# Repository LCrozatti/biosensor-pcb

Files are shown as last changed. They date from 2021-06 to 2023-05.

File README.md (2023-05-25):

# biosensor-pcb

Development of a printed circuit with NFC communication that performs cyclic voltammetry and chronoamperometry on printed electrodes with applications in amperometric biosensors.

## :books: Methodology

Kicad software will be used to make the printed circuit boards, and the first PCB has the purpose to test the code and noise involved in the sampling. The test board in question has its files in the `./placa-teste` directory. The designed test board is illustrated in the figure below:

<p align="center">
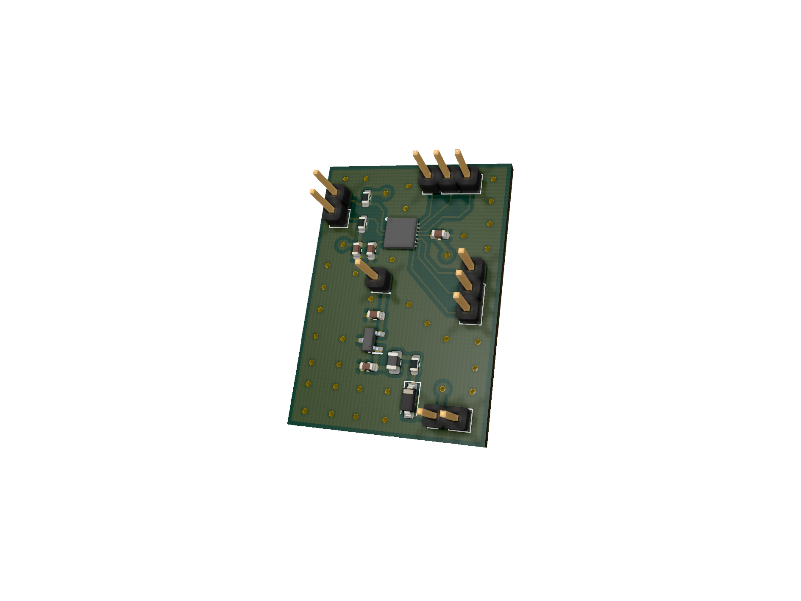
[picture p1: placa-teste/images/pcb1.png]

</p>

The first firmware involved was made based on code produced by [Linnes Lab](https://github.com/LinnesLab/LMP91000). Initially, an ATmega168PA-MU microcontroller will be used to control the potentiostat.

### :hammer: Tools

[Kicad](https://www.kicad.org/)

[C]()

[Python](https://www.python.org/)

[Jupyter](https://jupyter.org/)

[Numpy](https://numpy.org/)

[Pandas](https://pandas.pydata.org/)

[Matplotlib](https://numpy.org/)

<br />

### :test_tube: Data analysis

The data will be analyzed using the Python language, the file `./placa-teste/amostragem/eletroquimica.ipynb` contains some demonstrations on the use of python in cyclic voltammetry and chronoamperometry operations. The dataset used in this file can be accessed through the [IEEE Data Port](https://ieee-dataport.org/documents/supplementary-material-optimized-sampling-rate-voltammetry-based-electrochemical-sensing) [1].

<p align="center">
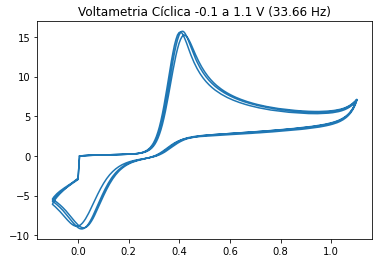
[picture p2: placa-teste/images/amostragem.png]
Amostragem

</p>

### :dart: Final prototype

The final board will have an antenna controlled by the *transponder* ST25DV64K, the control will be carried out by the microcontroller STM32L0 and the voltage control at the electrodes will be given through the programmable potentiostat LMP91000. The main study in this phase is the possibility of *energy harvesting*, leading to a circuit with low energy consumption.

### :iphone: App

The application in question will be built using the React-Native *framework*, along with the [react-native-nfc-manager](https://github.com/whitedogg13/react-native-nfc-manager) library. Its beginning has already been given with some reading tests..

<p align="center">
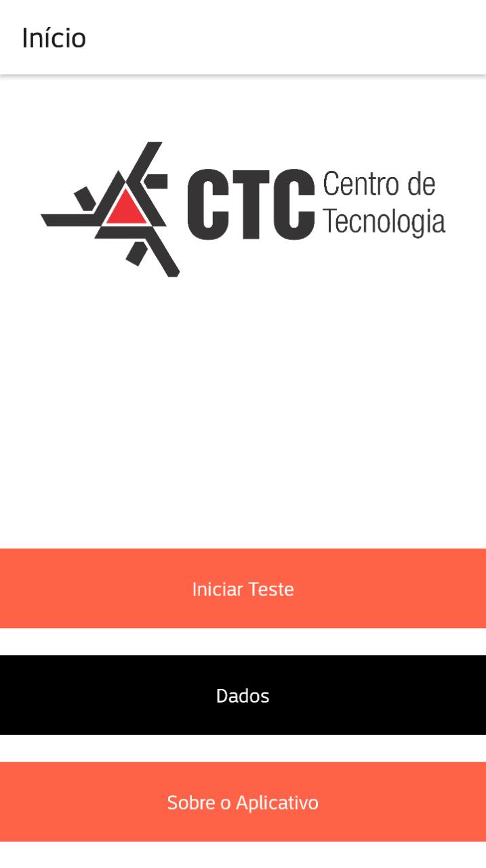
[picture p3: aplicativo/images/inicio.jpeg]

</p>

## :hourglass: Timeline

### 06/06/2021

The repository was created and updated with data from the test board.

### 13/09/2021

The soldering of the components has been completed and now some tests are being done to confirm the code. There were some problems in the negative polarization part and I will now work on the IntZ variable to make this possible (67% Vref - when we work with negative polarization). So the positive bias is working and it is possible to do a "half" cyclic voltammetry.

<p align="center">
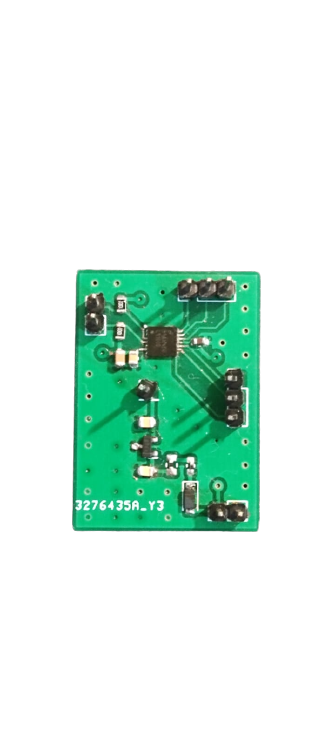
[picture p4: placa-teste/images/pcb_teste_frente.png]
placa_teste_frente

</p>

### 12/10/2021

Another test was made and is possible to see that the potential between WE and RE is sweeping among -490 mV and 490 mV, demonstrating that the board is well functioning (24% of the reference voltage that is 2.048 V = 491,52 mV). Showing that the circuit can perform cyclic voltammetry in Potassium Ferrocyanide.

### 26/01/2022

The first PCB with NFC communication was developed, is being tested and the code of STM32L031G6U6 will be published here. To project the antenna, i used as a reference the Application note - AN2972 from ST Instruments and with some calculations the theoretic inductance obtained was 2.79 µH. Measuring with the help of a Handheld LCR Meter - UT612, the experimental inductance was 2.6 µH being an percent error of 7.3%.

<p align="center">
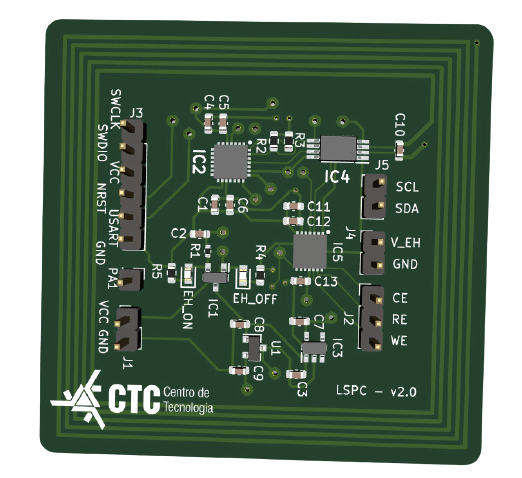
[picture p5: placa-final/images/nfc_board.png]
nfc_board

</p>

## References

[1] S. Aiassa, S. Carrara and D. Demarchi, "Optimized Sampling Rate for Voltammetry-Based Electrochemical Sensing in Wearable and IoT Applications," in IEEE Sensors Letters. doi: 10.1109/LSENS.2019.2918575.

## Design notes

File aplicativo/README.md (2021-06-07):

# aplicativo

Diretório que serão inseridos os códigos para a aplicação que permite a comunicação NFC.

# Requisitos

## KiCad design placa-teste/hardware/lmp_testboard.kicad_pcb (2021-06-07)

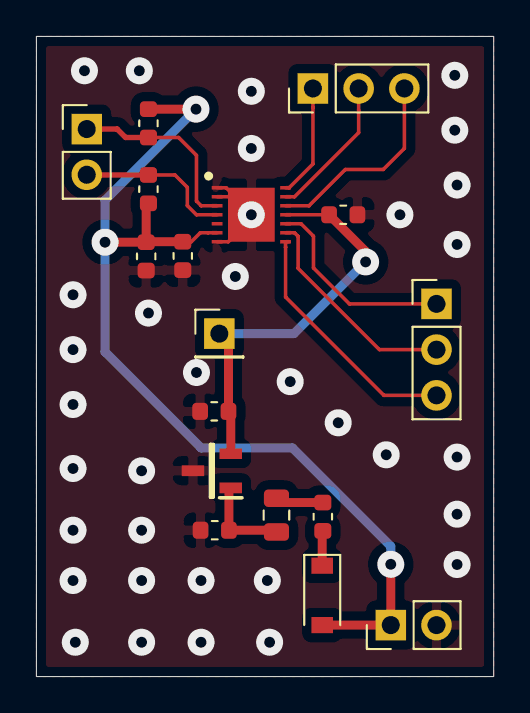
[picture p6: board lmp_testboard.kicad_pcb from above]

Board: 2 copper layers, 25.4 x 35.6 mm, 17 parts (0 on the bottom side), 14 nets.

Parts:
C1: 0.47 uF; C_0603_1608Metric
C2, C5: 0.1uF; C_0603_1608Metric
C3: 1uF; C_0603_1608Metric
C4: 2.2 uF; C_0603_1608Metric
D1: B5819W; D_SOD-123
F1: 500mA; Fuse_0603_1608Metric
FB1: 100 @ 100 MHz; L_0805_2012Metric
IC1: LMP91000SD_NOPB; LMP91000SDX_NOPB
J1, J2: Conn_01x02; PinHeader_1x02_P2.54mm_Vertical
J3, J4: Conn_01x03; PinHeader_1x03_P2.54mm_Vertical
J5: Conn_01x01; PinHeader_1x01_P2.54mm_Vertical
R2, R3: 2k2; R_0603_1608Metric
U1: REF3020; SOT95P237X112-3N

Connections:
A0: IC1.8, J4.3
C1: IC1.10, J4.1
C2: IC1.9, J4.2
CE: IC1.14, J3.1
GND: C1.2, C2.2, C3.2, C4.2, C5.2, IC1.1, IC1.2, IC1.7, IC1.15, J1.2, U1.3
unnamed: C1.1, FB1.1, U1.1
unnamed: D1.1, F1.1
unnamed: F1.2, FB1.2
RE: IC1.13, J3.2
SCL: IC1.3, J2.1, R2.2
SDA: IC1.4, J2.2, R3.2
VCC: C4.1, C5.1, D1.2, IC1.6, J1.1, R2.1, R3.1
VREF: C2.1, C3.1, IC1.11, J5.1, U1.2
WE: IC1.12, J3.3

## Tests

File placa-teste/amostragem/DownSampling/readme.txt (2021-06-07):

%%%%%%%%%%%%%%%%%%%%%%%%%%%%%%%%%%%%%%%%%%%%%%%%%%%%%%%%%%%%%%%%%   
%      Simone AIASSA                  
% Politecnico di Torino, Turin, Italy 
% EPFL, Lausanne, Switzerland         
%                          27.05.2019 
%
%%%%%%%%%%%%%%%%%%%%%%%%%%%%%%%%%%%%%%%%%%%%%%%%%%%%%%%%%%%%%%%%%

DISCLAIMER:
TO USE THIS DATA YOU HAVE TO CITE THE AUTHOR AS FOLLOW:

[] S. Aiassa, S. Carrara and D. Demarchi, "Optimized Sampling Rate for Voltammetry-Based Electrochemical Sensing in Wearable and IoT Applications," in IEEE Sensors Letters. doi: 10.1109/LSENS.2019.2918575.

The dataset contains Scan Cyclic Voltammetry (SCV) and Differential Pulse Voltammetry (DPV) waveform, obtained from APAP (Paracetamol) samples, considering different sampling rate. The data are provided to the reader "as is", for more detail on the set-up, the chemicals and materials refer to [1].

The DownSampling.zip folder contains the following file:

- SCV.mat contains seven cells, one per every sampling rate in the range [33,66:0,58] Hz named CV[sampling_rate]. Any of this cell is composed of seven calibration point, acquired respectively sensing sample of [0,50,100,150,200,250,300] µM of APAP. Every cell contains a matrix composed of a couple of coordinates, the first column, x-axis, is the voltage (V), and the second column, y-axis, is the current (µA). The matrix describes the full Scav Cyclic Voltammogram acquired at the given condition, every voltammogram is repeated three times to consider inter-electrode variability and avoid artefact. 

- DPV.mat contains seven cells, one per every sampling rate in the range [16,83:0,29] Hz named DPV[sampling_rate]. Any of this cell is composed of seven calibration point, acquired respectively sensing sample of [0,50,100,150,200,250,300] µM of APAP. Every cell contains a matrix composed of a couple of coordinates, the first column, x-axis, is the voltage (V), and the second column, y-axis, is the current (µA). The matrix describes the full Differential Pulse Voltammogram acquired at the given condition, every voltammogram is repeated three times to consider inter-electrode variability and avoid artefact.

- openfile.m helps the user to import and plot data in Matlab.

- readme.txt contains this information.

[1] S. Aiassa, S. Carrara and D. Demarchi, "Optimized Sampling Rate for Voltammetry-Based Electrochemical Sensing in Wearable and IoT Applications," in IEEE Sensors Letters. doi: 10.1109/LSENS.2019.2918575.

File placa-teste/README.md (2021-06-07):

# placa-teste

Arquivos da primeira placa projetada.

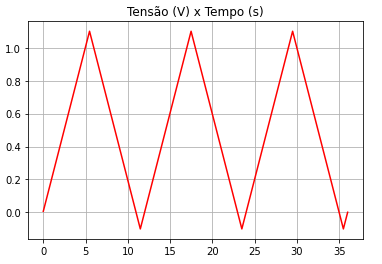
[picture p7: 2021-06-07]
placa-teste/images/amostragem2.png

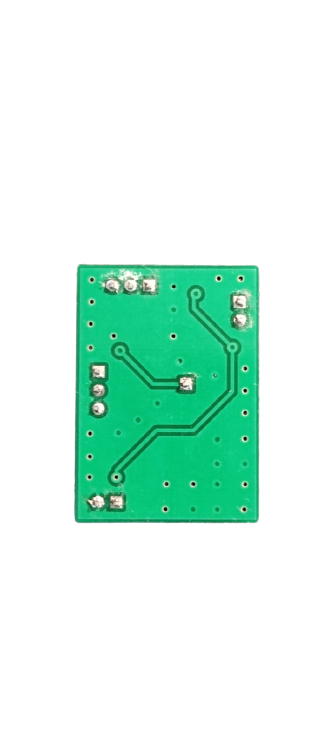
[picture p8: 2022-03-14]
placa-teste/images/pcb_teste_traseira.png

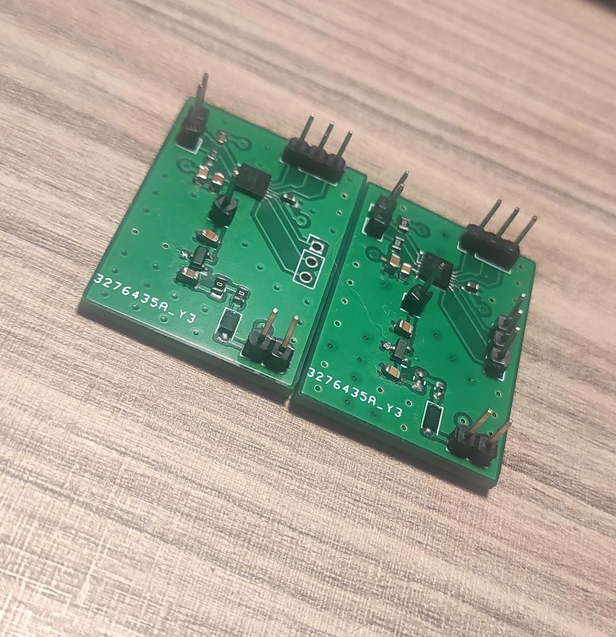
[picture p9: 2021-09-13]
placa-teste/images/placa_1.png

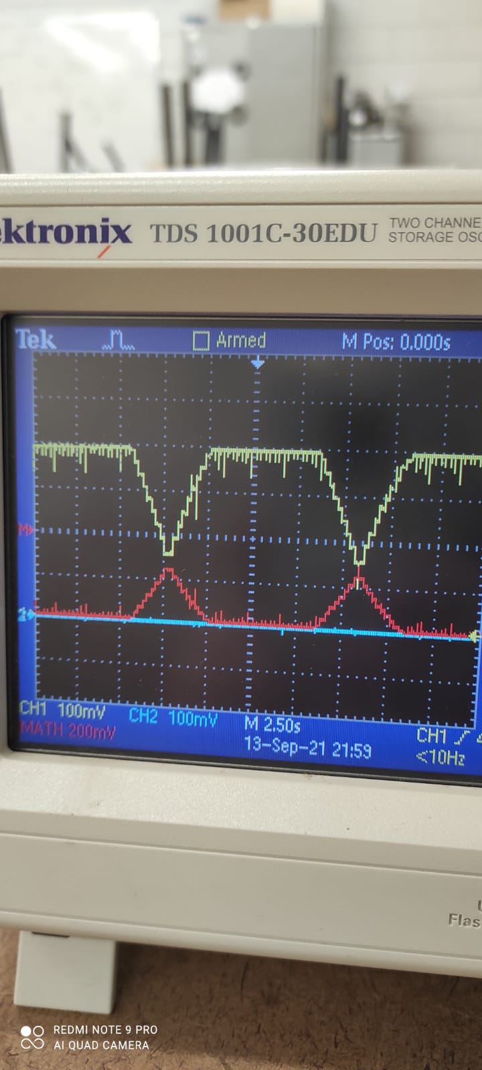
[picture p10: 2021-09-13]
placa-teste/images/osciloscopio_1.png

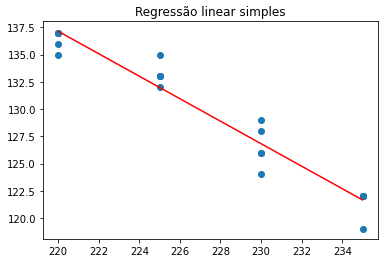
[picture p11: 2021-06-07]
placa-teste/images/amostragem3.png

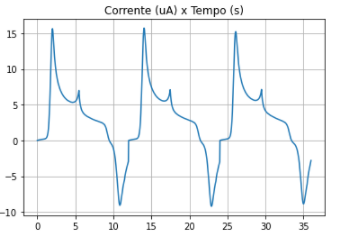
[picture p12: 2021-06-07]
placa-teste/images/amostragem4.png

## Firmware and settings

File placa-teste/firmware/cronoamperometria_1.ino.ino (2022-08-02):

#include <LMP91000.h>
#include <Wire.h>

LMP91000 pStat = LMP91000();

int16_t opVolt = 3300; //milliVolts se esta trabalhando com a tensão de 3,3 V
uint8_t resolution = 10; //10-bits (resolução do microcontrolador)

void setup()
{
  
  Wire.begin(); //Inicia a comunicacação I2C
  Serial.begin(9600); // Inicia o compartilhamento de dados na Serial

  pStat.standby(); 
  
  // Modo de standby = ?
  /*
   * 
   * 
   */
   
  delay(1000); // Não é necessário, talvez um delay mínimo de 50 - 100 ms para não travar a I2C
  
  // Inicia a função de cronoamperometria
  runAmp(2, 0, 5000, 66, 5000, 250, 5000, 80, 6);
  /*
   * Função: runAmp
   * 
   * Objetivo: Plotar dados de tensão, tempo, corrente do processo de cronoamperometria
   *           para analisar dados com o uso da equação de cottrel
   *           
   * Entradas: user_gain (Ganho), pre_stepV (tensão inicial (V0)), 
   *           quietTime (tempo morto para a tensão inicial), v1 (primeiro step de tensão em mV),
   *           t1 (tempo para o primeiro step de tensão em ms), v2 (segundo step de tensão em mV), 
   *           t2 (tempo para o segundo step de tensão em ms), samples (número de amostras), range (unidade de corrente)
   *           range = 12 is picoamperes
               range = 9 is nanoamperes
               range = 6 is microamperes
               range = 3 is milliamperes
       
   * Saídas: Tensão, tempo, corrente
   * 
   */
}


void loop()
{
}


//range = 12 is picoamperes
//range = 9 is nanoamperes
//range = 6 is microamperes
//range = 3 is milliamperes

void runAmp(uint8_t user_gain, int16_t pre_stepV, uint32_t quietTime, int16_t v1,
            uint32_t t1, int16_t v2, uint32_t t2, uint16_t samples, uint8_t range)
{
  /*pStat.disableFET(); // MODECN[7] = 0
  pStat.setGain(user_gain); // TIACN[4:2] = 2 = 010 => 3.5kOhm
  pStat.setRLoad(0); // TIACN[1:0] = 0 = 10 Ohm
  pStat.setIntRefSource(); // REFCN[7] = 1 => Interno (Vcc)
  pStat.setIntZ(1); // REFCN[6:5] = 01 => 50% Zero interno
  pStat.setThreeLead(); // MODECN[2:0] = 011 => Três eletrodos
  pStat.setBias(0); // REFCN[3:0] = 0 = 0% de polarização */

  pStat.unlock();
  pStat.write(LMP91000_TIACN_REG,0b00010100);      // Rload = 10ohm, TIA_Gain = 35kohm
  pStat.write(LMP91000_REFCN_REG,0b10110000);      // ExtRef, IntZ = 20%, Inicia neg, 0% bias 
  pStat.write(LMP91000_MODECN_REG,0b00000011);     // FET_Short = 0, 3-lead amperometric

  Serial.print("STATUS: ");
  Serial.println(pStat.read(LMP91000_STATUS_REG),HEX);
  Serial.print("TIACN: ");
  Serial.println(pStat.read(LMP91000_TIACN_REG),HEX);
  Serial.print("REFCN: ");
  Serial.println(pStat.read(LMP91000_REFCN_REG),HEX);
  Serial.print("MODECN: ");
  Serial.println(pStat.read(LMP91000_MODECN_REG),HEX);
  
  //Print column headers
  String current = "";
  if(range == 12) current = "Current(pA)";
  else if(range == 9) current = "Current(nA)";
  else if(range == 6) current = "Current(uA)";
  else if(range == 3) current = "Current(mA)";
  else current = "SOME ERROR";
  
  Serial.println("Voltage(mV),Time(ms)," + current);

  int16_t voltageArray[3] = {pre_stepV, v1, v2};
  uint32_t timeArray[3] = {quietTime, t1, t2};

  //i = 0 -> tensão inicial
  //i = 1 -> potencial de redução
  //i = 2 -> potencial de oxidação
  
  for(uint8_t i = 0; i < 3; i++)
  {

    // Calcula o tempo para uma amostra, não confundir com frquencia de amostragem
    // Sugestão: mudar de fs para ts (time sampling)
    
    uint32_t fs = timeArray[i]/samples;

    
    // Chama a função para encontrar o valor mais proximo de polarização para os valores dos 2 steps de entrada
    voltageArray[i] = determineLMP91000Bias(voltageArray[i]);

     /*
     * Função: determineLMP91000Bias(voltageArray[i])
     * 
     * Objetivo: Retorna um novo valor da posição do registro TIA_BIAS, para ser a polarização correta 
     * e sua porcentagem para alcançar o valor próximo de tensão redox desejada.
     * 
     * Entradas: voltageArray[i]
     *           i = 0 -> tensão inicial
                 i = 1 -> tensão de redução
                 i = 2 -> tensão de oxidação
     * Saídas: retorna +-posicao_TIA_BIAS.
     * 
     * 
     */
    
    // Seleciona o sinal da polaridade  
    // Ponto para otimizar: Na função determineLMP91000Bias ele já verifica o sinal
    // por que não setar esse parâmetro antes?
    
    if(voltageArray[i] < 0) pStat.setNegBias();
    else pStat.setPosBias();

    // Usa o millis nessa parte, para ter a captura do tempo, que é uma variável importante para
    // a análise por Equação de Cottrel
    
    unsigned long startTime = millis();
    
    // Seta a polarização/%Vref
    
    pStat.setBias(abs(voltageArray[i]));
    while(millis() - startTime < timeArray[i])
    {
      Serial.print((uint16_t)(opVolt*TIA_BIAS[abs(voltageArray[i])]*(voltageArray[i]/abs(voltageArray[i]))));
      // Sugestão de alteração
      // Serial.print((uint16_t)(opVolt*TIA_BIAS[abs(voltageArray[i])]));
      
      Serial.print(",");
      Serial.print(millis());
      Serial.print(",");
      analog = analogRead(A0);
      float corrente_ua = ((((analog*5.0)/1024.0) - 2.048)/(35000.0))*1000000.0;
      Serial.println(corrente_ua);

      // pStat.getCurrent(pStat.getOutput(A0), opVolt/1000.0, resolution)
      // Ele lê o valor analógico de A0, converte esse valor na tensão de saída do amplificador de transimpedância, 
      // para depois converter em corrente de acordo com a equação que depende do ganho do amplificador. 

      // delay para o tempo de cada amostra
      delay(fs);
    }
  }

  // Termina com 0 V
  pStat.setBias(0);
}


signed char determineLMP91000Bias(int16_t voltage)
{

  // Define o sinal de tensão
  
  signed char polarity = 0;
  if(voltage < 0) polarity = -1;
  else polarity = 1;

  // Variaveis da função v1, v2 (não-globais), para manipulação de dados
  int16_t v1 = 0;
  int16_t v2 = 0;

  // Coleta o módulo do valor de tensão em mV 
  
  voltage = abs(voltage);

  if(voltage == 0) return 0;

  // Iteração for, testando possíveis tensões que o potenciostato possa atingir
  // (compara com [i] e [i+1] para ver se o valor está dentro), de acordo com a tensão de referência,
  // ao qual o potenciostato possa atingir.
   
  for(int i = 0; i < NUM_TIA_BIAS-1; i++)
  {
    v1 = opVolt*TIA_BIAS[i];
    v2 = opVolt*TIA_BIAS[i+1];

    if(voltage == v1) return polarity*i;
    else if(voltage > v1 && voltage < v2)
    {
      if(abs(voltage-v1) < abs(voltage-v2)) return polarity*i;
      else return polarity*(i+1);
    }
  }
  return 0;
}

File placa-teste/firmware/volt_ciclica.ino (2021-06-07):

#include <LMP91000.h> // Biblioteca LMP91000 para Arduino (Fonte: Linnes Lab/MIT)
#include <Wire.h> // Biblioteca para comunicação I2C - Arduino

LMP91000 pstat = LMP91000();

int rate = 200; // Taxa de amostragem;
int settling_time = 50; // Tempo que a tensão fica constante;

void setup()
{
  Wire.begin(); 
  
  // Inicia a comunicação I2C;
  
  Serial.begin(9600);

  delay(50);
  pstat.standby(); // Procedimento, função sem parâmetro
  
  // Modo operacional de StandBy.
  
  delay(50);
  pstat.disableFET(); // Procedimento, função sem parâmetro
  
  // "enable and disable FET for deep sleep mode".
  
  pstat.setGain(1);
  
  //parametro - valor - resultado
  //0 - 000 - Resistor Externo//1 - 001 - 2.75 kOhm//2 - 010 - 3.5 kOhm//3 - 011 - 7 kOhm
  //4 - 100 - 14 kOhm//5 - 101 - 35 kOhm//6 - 110 - 120 kOhm //7 - 111 - 350 kOhm
  
  pstat.setRLoad(0); 
  
  //0 - 00 - 10 Ohm //1 - 01 - 33 Ohm //2 - 10 - 50 Ohm //3 - 11 - 100 Ohm
  
  pstat.setExtRefSource(); // Procedimento, função sem parâmetro
  
  //Desbloqueia o registro REFCN para o modo "write". Primeiro lê o registro para
  //assegurar que os outros bits nao foram afetados. Escreve 1 para o sétimo bit do
  //registro do REFCN. Indica a tensão de referência para o pino Vref;
  
  pstat.setIntZ(1);
  
  //Esta função tem o objetivo de setar o "zero interno", principalmente do amplificador
  //de transimpedância
  //0 - 00 - 0.2*V_REF
  //1 - 01 - 0.5*V_REF
  //2 - 10 - 0.67*V_REF
  //3 - 11 - bypassed

 
  pstat.setThreeLead(); // Procedimento, função sem parâmetro
  // Modo de operação de 3 eletrodos
  
  delay(2000); //Setando as condições iniciais para a voltametria cíclica
  
  // Inicio da Voltametria Cíclica, iterando 3 vezes. 
  
  // -------- PARTE PASSÍVEL DE ALTERAÇÃO -------- //
  for (int j = 0; j < 3; j++)
  {
    pstat.setNegBias(); // Polaridade (-);
    for (int i = 1; i < 11; i++)
    {
      pstat.setBias(i); 
      //const double TIA_BIAS[] = {0, 0.01, 0.02, 0.04, 0.06, 0.08, 0.1, 0.12, 0.14,
      //0.16, 0.18, 0.2, 0.22, 0.24}; "i" pode ir de 0 a 13, se "i" for maior que 13 --> i = 0
      delay(settling_time); // Tempo que a tensão fica constante;
      Serial.print(i*-1);
      Serial.print(",");
      delay(1);
      Serial.println(analogRead(A0)); // Leitura da corrente I_OUT = (V_REF - V_OUT)/R_TIA
      delay(rate);
    }
    for (int i = 10; i >= 0; i--)
    {
      pstat.setBias(i);
      //delay(50);
      delay(settling_time); // Tempo que a tensão fica constante;
      Serial.print(i*-1);
      Serial.print(",");
      delay(1);
      Serial.println(analogRead(A0)); // Leitura da corrente I_OUT = (V_REF - V_OUT)/R_TIA
      delay(rate);
    }
    pstat.setPosBias(); // Polaridade (+);
    for (int i = 1; i < 11; i++)
    {
      pstat.setBias(i);
      //delay(50);
      delay(settling_time); // Tempo que a tensão fica constante;
      Serial.print(i*1);
      Serial.print(",");
      delay(1);
      Serial.println(analogRead(A0)); // Leitura da corrente I_OUT = (V_REF - V_OUT)/R_TIA
      delay(rate);
    }
    for (int i = 10; i >= 0; i--)
    {
      pstat.setBias(i);
      //delay(50);
      delay(settling_time); // Tempo que a tensão fica constante;
      Serial.print(i*1);
      Serial.print(",");
      delay(1);
      Serial.println(analogRead(A0)); // Leitura da corrente I_OUT = (V_REF - V_OUT)/R_TIA
      delay(rate);
    }
  }
  
  pstat.setBias(0);

}

void loop() {
  

}
